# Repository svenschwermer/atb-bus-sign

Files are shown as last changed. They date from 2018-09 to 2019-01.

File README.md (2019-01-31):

# AtB Bus Sign

_Scrolling LED bus sign for Trondheim based AtB bus stops._

## Hardware
* [Mediatek LinkIt Smart 7688][1]
* 32×8 LED matrix display with 4 daisy-chained [MAX7219][2]-compatible controllers

```
LinkIt Smart 7688                      Display
┌───────────────┐                      ┌─────┐
│            5V ├──────────────────────┤ VCC │
│           GND ├──────────────────────┤ GND │
│           3V3 ├──────────┐           │     │
│               │         ┌┴┐          │     │
│               │     10k │R│          │     │
│               │         └┬┘          │     │
│  P25, SPI_CS1 ├──────────┴───────────┤ CS  │
│  P24, SPI_CLK ├──────────────────────┤ CLK │
│ P22, SPI_MOSI ├──────────────────────┤ DIN │
└───────────────┘                      └─────┘
```

### Gotchas
* The MAX7219 has a LOAD latch pin instead of a classic chip select pin (MAX7221).
* Having long traces on the SPI lines (CLK, MOSI) seems to cause trouble when
  Linux accesses the flash which hangs on the same SPI bus. JFFS errors are the
  result. Reducing the SPI clock frequency from 40 MHz to 1 MHz fixed this issue.
  This is probably overly conservative. A patch that makes the necessary changes
  is provided via the patch file in the root directory of this repository.

## Software
This software has been tested with OpenWrt v18.06.1. To build the entire image, do the following:
```
$ ./build.sh
```

## Housing
A simple housing is available in the `housing` directory. A bit of perfboard
holds the Linkit Smart 7688 module. 

[1]: https://docs.labs.mediatek.com/resource/linkit-smart-7688
[2]: https://datasheets.maximintegrated.com/en/ds/MAX7219-MAX7221.pdf

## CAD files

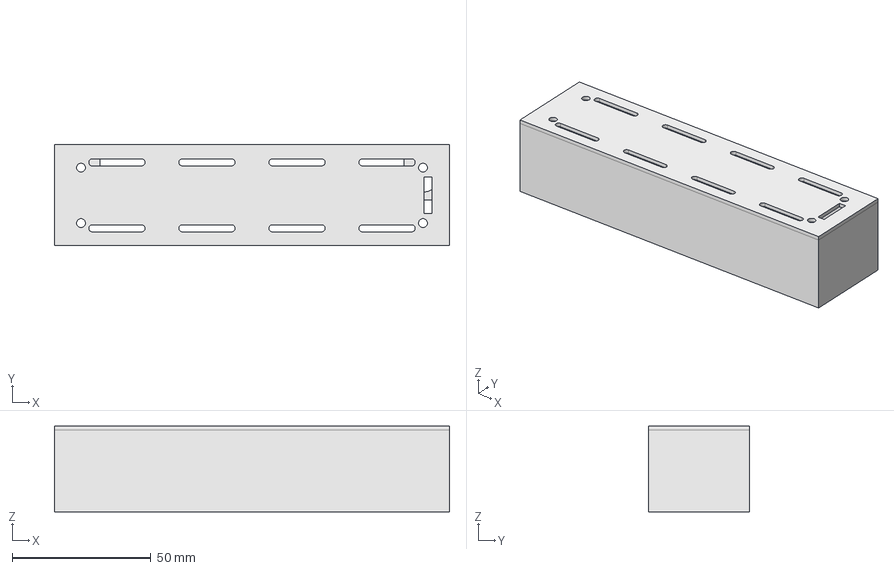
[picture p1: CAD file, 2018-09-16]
housing/bus-sign.fcstd
142.5 x 36.3 x 31.0 mm

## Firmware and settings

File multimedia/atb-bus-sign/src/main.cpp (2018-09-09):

#include "max7219.h"
#include "sign.h"

#include <iostream>

int main() {
  try {
    max7219 max("/dev/spidev0.1", 4);
    max.init();
    bus_sign([&max](const frame &f) { max.display(f); });
  } catch (const std::exception &e) {
    std::cerr << "Error: " << e.what() << '\n';
    return 1;
  }
  return 0;
}

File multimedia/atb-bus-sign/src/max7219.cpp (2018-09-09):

#include "max7219.h"

#include <linux/spi/spidev.h>
#include <linux/types.h>

#include <fcntl.h>
#include <sys/ioctl.h>
#include <sys/stat.h>
#include <sys/types.h>
#include <unistd.h>

#include <cstring>
#include <initializer_list>
#include <system_error>
#include <vector>

max7219::max7219(std::string device, int cascade)
    : cascade(cascade), spi_dev_fd(::open(device.c_str(), O_RDWR)) {
  if (spi_dev_fd == -1)
    throw std::system_error(errno, std::generic_category());

  auto mode = spi_mode;
  if (::ioctl(spi_dev_fd, SPI_IOC_WR_MODE, &mode) < 0)
    throw std::system_error(errno, std::generic_category());
}

max7219::~max7219() {
  if (spi_dev_fd != -1)
    ::close(spi_dev_fd);
}

void max7219::init() {
  std::initializer_list<std::pair<reg, uint8_t>> sequence{
      {reg::decode_mode, 0x00},  // No decoding
      {reg::intensity, 0x01},    // Minimal intensity
      {reg::scan_limit, 0x07},   // Scan all digits (0..7)
      {reg::display_test, 0x00}, // Disable display test
      {reg::shutdown, 0x01},     // Normal operation
  };
  for (const auto x : sequence)
    write_to_all(x.first, x.second);
}

void max7219::display(const frame &f) {
  auto bytes = f.concatenated_lines();
  if (bytes.size() != 8 * cascade)
    throw std::runtime_error(__func__);
  for (int line = 0; line < 8; ++line) {
    auto line_data = bytes.data() + line * cascade;
    display_line(line, line_data);
  }
}

void max7219::spi_transfer(const uint8_t *data, int length) {
  std::vector<uint8_t> rx_buf(length);
  struct spi_ioc_transfer xfer;
  memset(&xfer, 0, sizeof(xfer));
  xfer.tx_buf = reinterpret_cast<uint64_t>(data);
  xfer.rx_buf = reinterpret_cast<uint64_t>(rx_buf.data());
  xfer.len = length;
  xfer.speed_hz = speed_hz;
  xfer.bits_per_word = bits_per_word;

  if (::ioctl(spi_dev_fd, SPI_IOC_MESSAGE(1), &xfer) < 0)
    throw std::system_error(errno, std::generic_category());
}

void max7219::write_to_all(reg r, uint8_t data) {
  std::vector<uint8_t> buf(2 * cascade);
  for (int i = 0; i < cascade; ++i) {
    buf[2 * i] = static_cast<uint8_t>(r);
    buf[2 * i + 1] = data;
  }
  spi_transfer(buf.data(), buf.size());
}

void max7219::display_line(int line, const uint8_t *data) {
  if (line < 0 || line > 7)
    throw std::runtime_error(__func__);
  std::vector<uint8_t> buf(2 * cascade);
  for (int i = 0; i < cascade; ++i) {
    buf[2 * i] = static_cast<uint8_t>(line + 1);
    buf[2 * i + 1] = data[i];
  }
  spi_transfer(buf.data(), buf.size());
}

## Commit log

2018-07-05 Current state of procd service file
2018-07-05 Use fixed exp/io/spi for MIPS
2018-08-07 Always provide read buffer
    Works just like with x/exp/io/spi now.
2018-08-19 Frame code ported
2018-09-11 Add CS pull-up to schematics
2018-09-16 Add 3D model for housing
    [bus-sign.fcstd]
2018-09-16 Add patch to limit flash SPI speed
